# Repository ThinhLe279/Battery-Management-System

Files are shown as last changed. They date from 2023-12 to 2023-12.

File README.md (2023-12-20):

# BATTERY MANAGEMENT SYSTEM 
This project repository contains the firmware for the Battery Management System (BMS), utilizing an `STM32L152RE` microcontroller board to oversee the conditions of four LiFePo4 cells arranged in series, including voltage, current, and temperature. Depending on the monitored conditions, the microcontroller directs the battery current flow into charging-only, discharging-only, or bidirectional modes. A Modbus slave/server protocol was implemented for data communication. A Python script acting as a Modbus Master was created on a Raspberry Pi to serve as a gateway, retrieving status data from the BMS and transmitting it to the cloud for visualization. Grafana was employed as the cloud service for visualization purposes.

## Table of Content  
	
	1. Main Equipment and Components 

	2. Functionalities

	3. Details 

## 1. Main Equipments and Components

* `STM32L152RE` (development board)
* `RASPBERRY PI`
* OP AMPS `LM342`
* MOSFET `FDS6898AZ`
* Multiplexer `4051BE`
* Shunt Resistor `WLBR010FE`
* Temperature Sensor `LM35DZ`

## 2. Functionalities

The Battery Management System (BMS) oversees and regulates multiple facets of the battery's condition to ensure both safety and optimal functionality, covering:
* Voltage Monitoring:
	* Tracking the individual cell and theoverall voltage of the battery.
* Temperature Monitoring:
	* Supervise Environment and Battery Pack's temperature.
* Current Supervision:
	* Overseeing the direction and intensity of current flow in and out of the battery. pack.
* Cell Balancing:
	* Maintaining a balanced state among the battery cells.
* Charging and Discharging Management:
	* Regulate MOSFETS to control the charging and discharging states of the battery.

## 3. Details
### Prerequisites
The project requirements: `MOSFET` driven switch (both charging and discharging) Temperature monitoring Individual battery cell voltages STM32 controller with over/under voltage per cell, over/under temperature (charge: 0C to 40C and discharge: -20C to 40C) Communication of cell voltages/temperatures/... over Modbus RTU protocol with the `STM32L152RE` functioning as a Slave and the `Raspberry Pi` serving as the Master.

Presentation of data on Grafana through a Docker container on the Raspberry Pi.

### Project diagram 

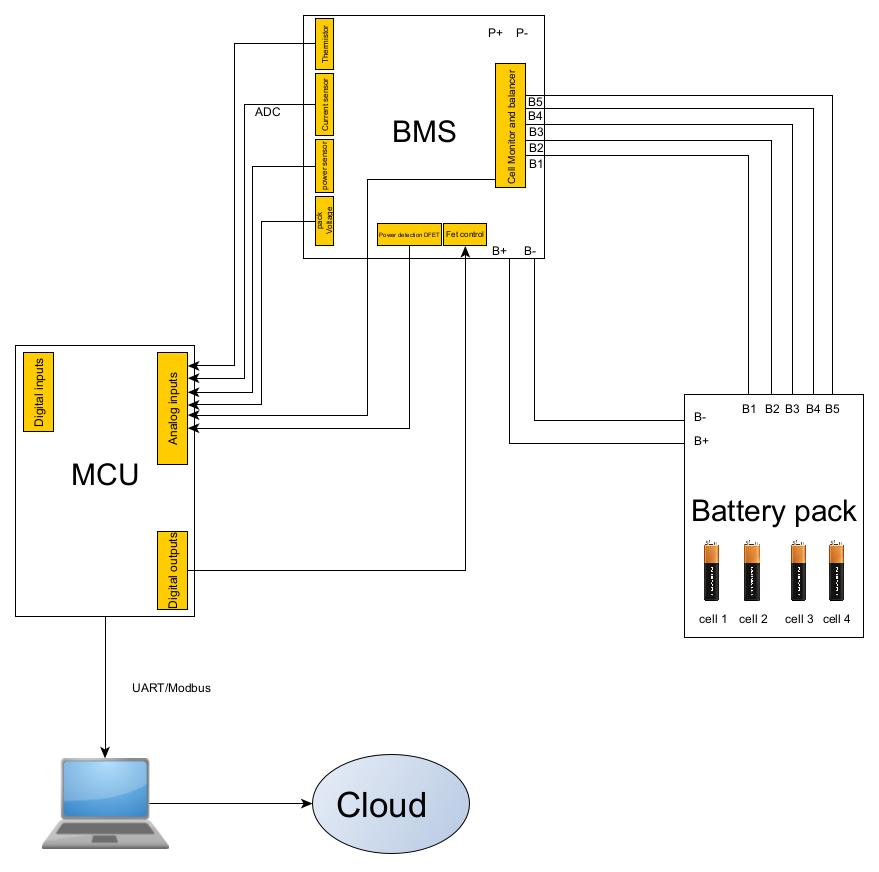
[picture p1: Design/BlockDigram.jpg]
diagram


### visualization

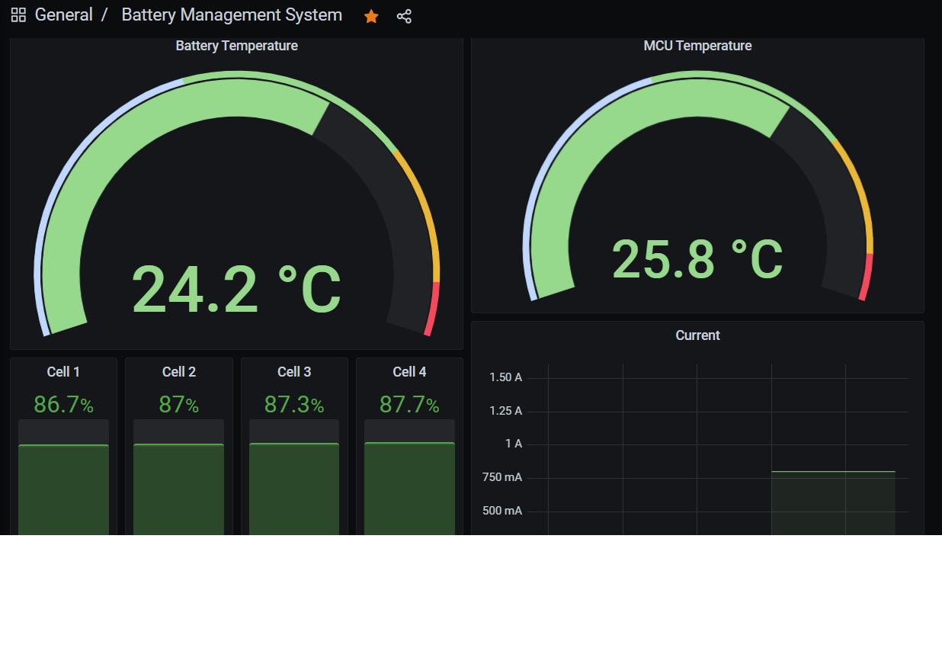
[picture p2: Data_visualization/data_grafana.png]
display


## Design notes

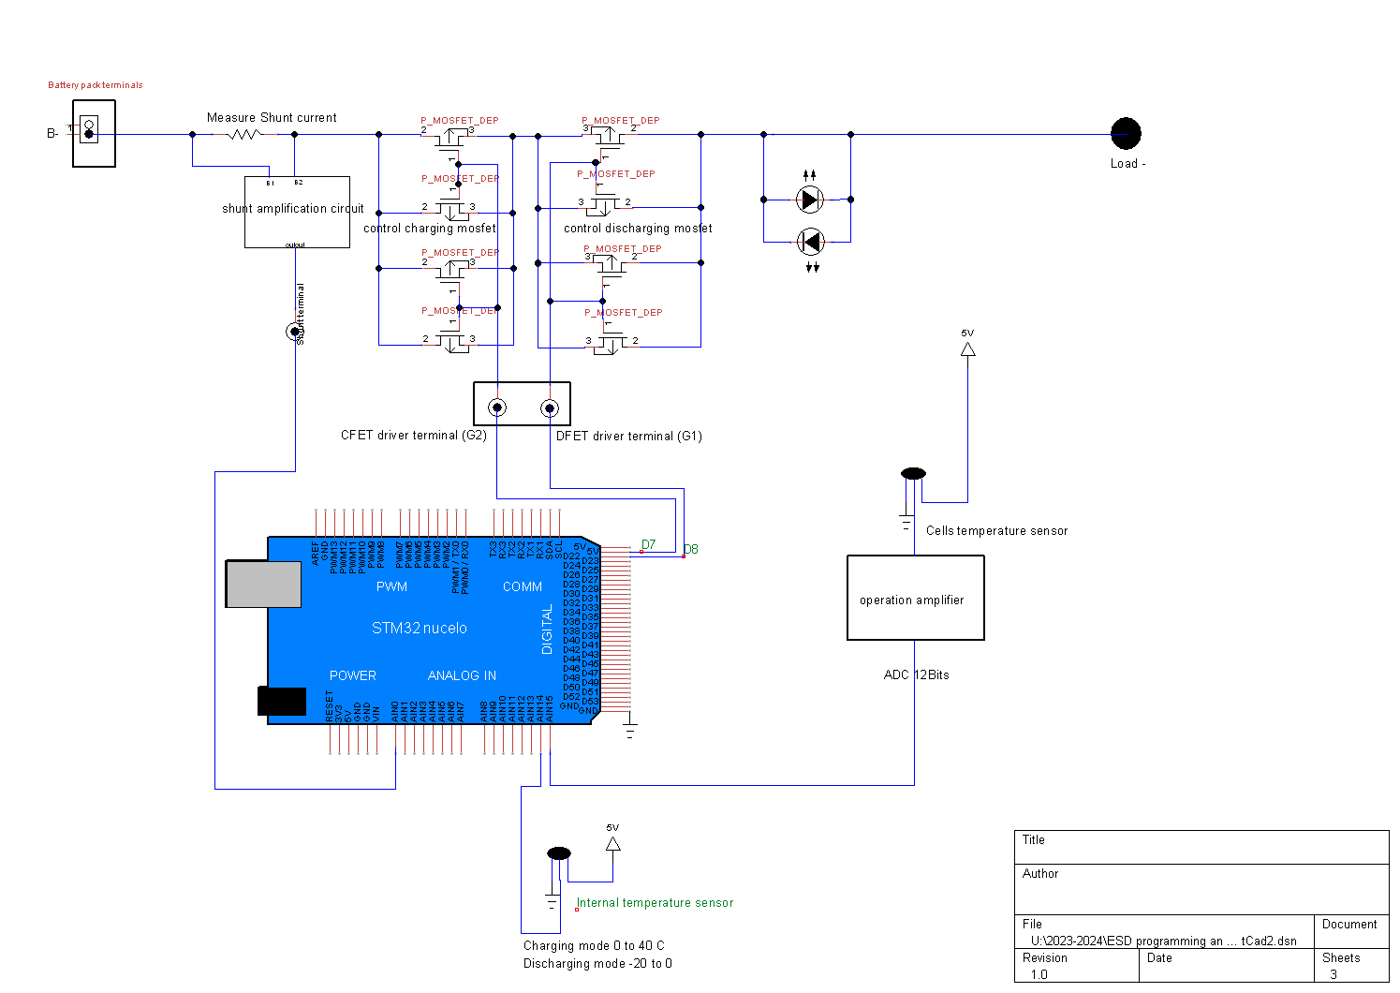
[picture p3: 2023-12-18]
schematic/IMG/tCad2.png

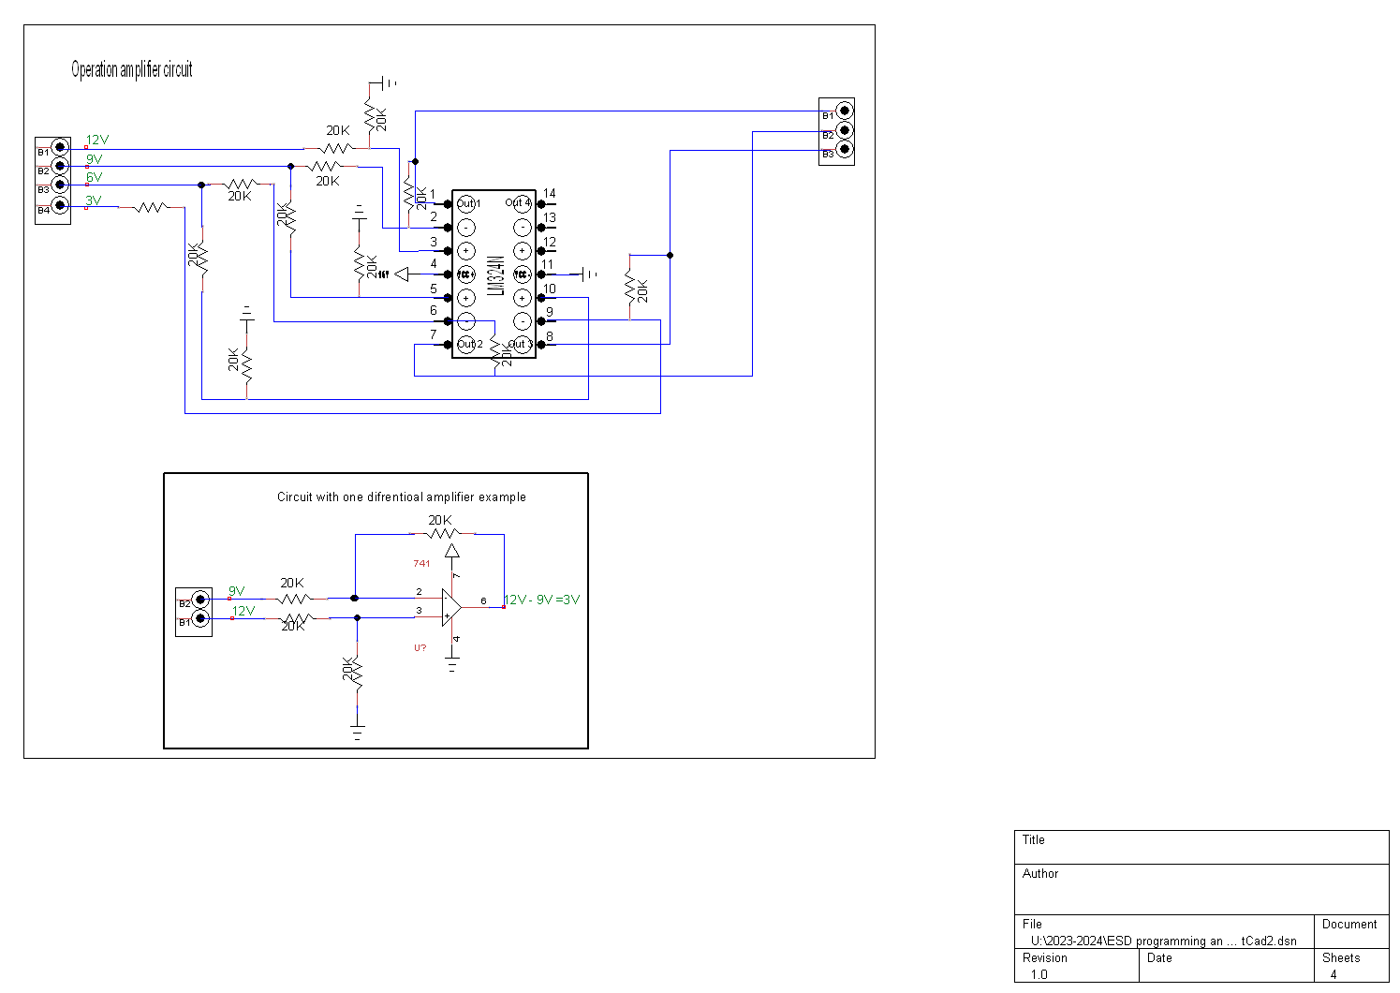
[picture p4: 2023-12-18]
schematic/IMG/Cells Voltages.png

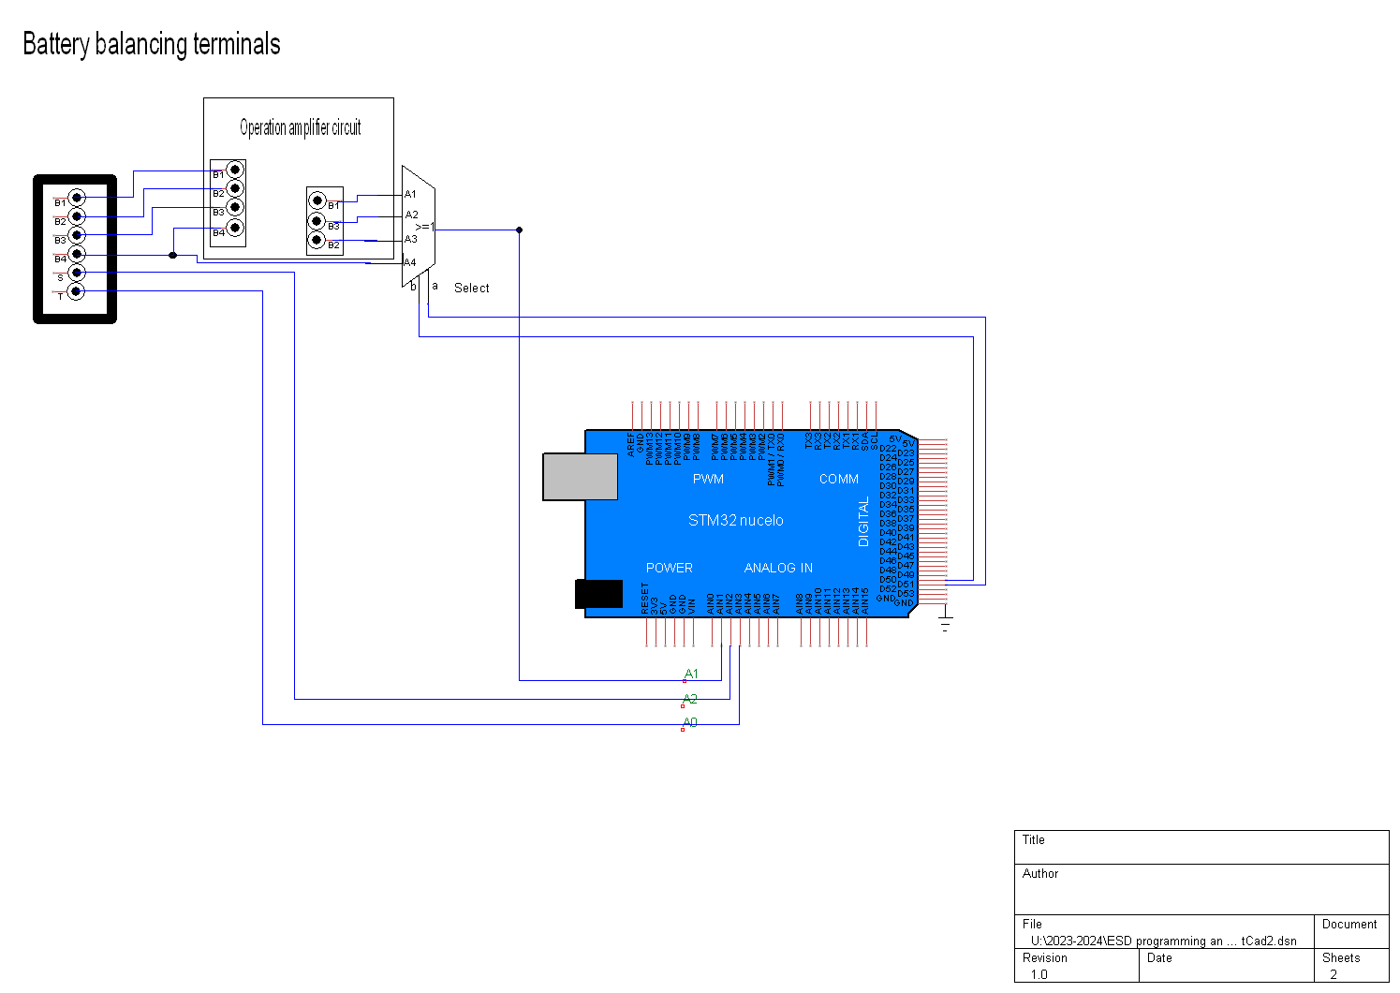
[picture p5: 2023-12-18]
schematic/IMG/MUX Connections.png

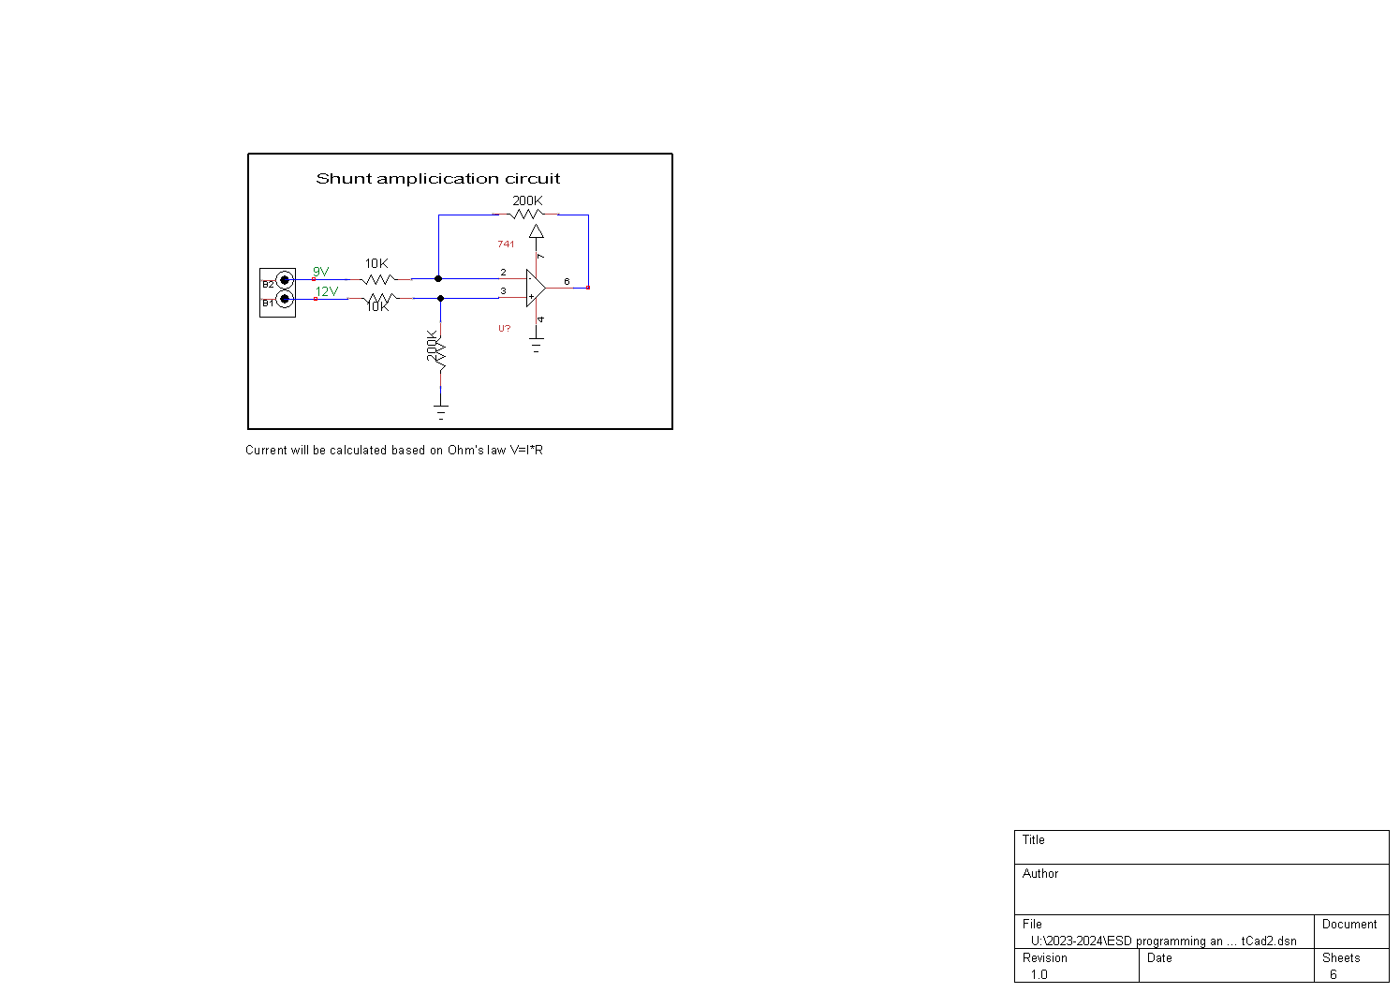
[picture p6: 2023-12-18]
schematic/IMG/Shunt amp circuit.png

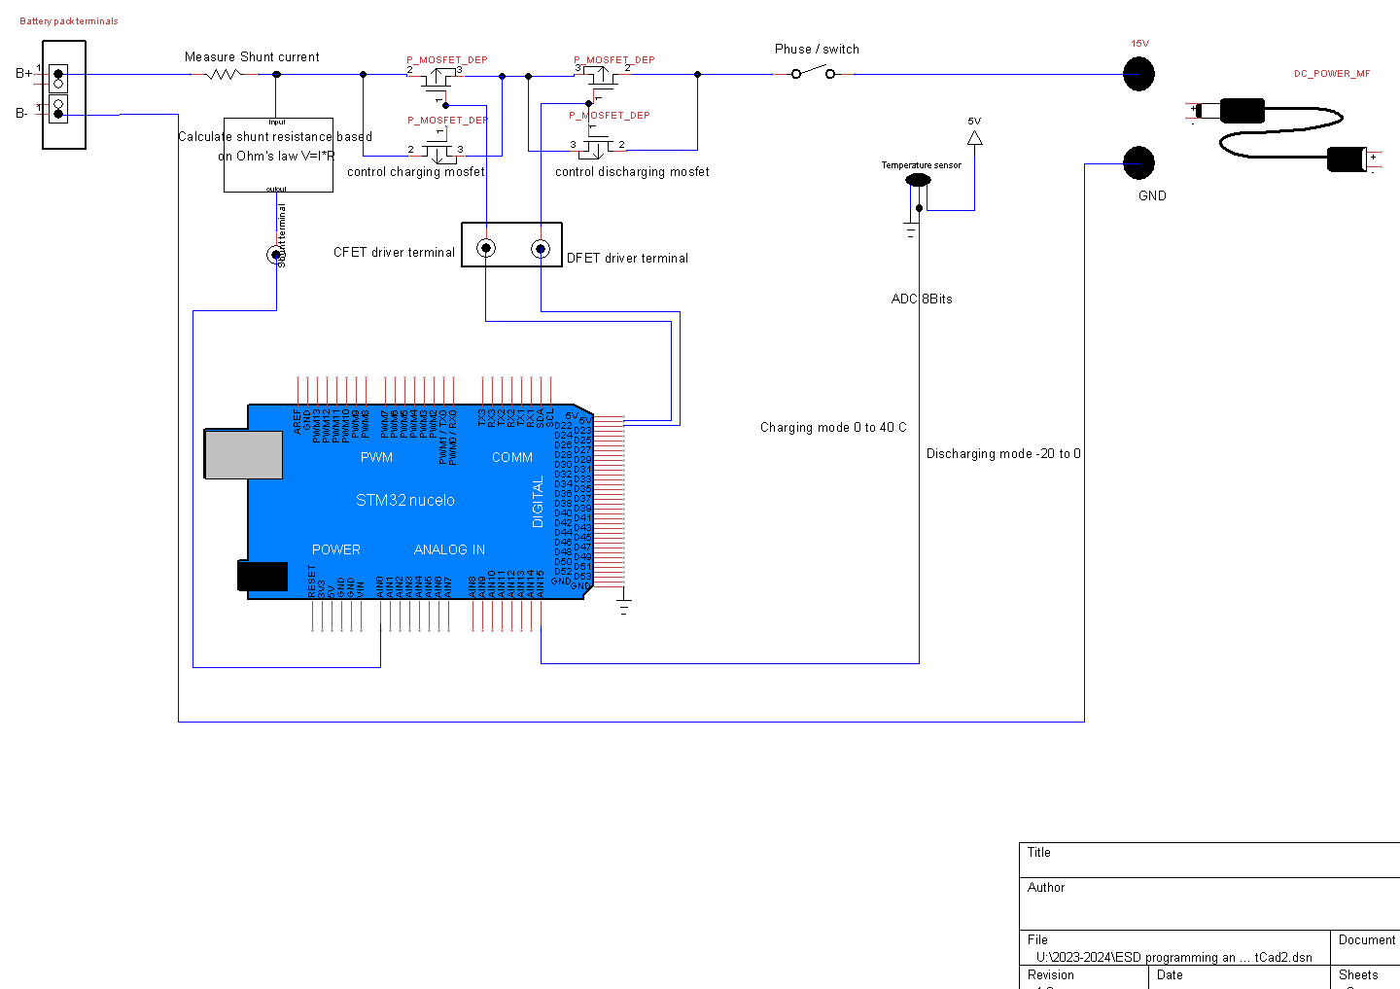
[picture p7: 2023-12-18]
schematic/IMG/SOC.png

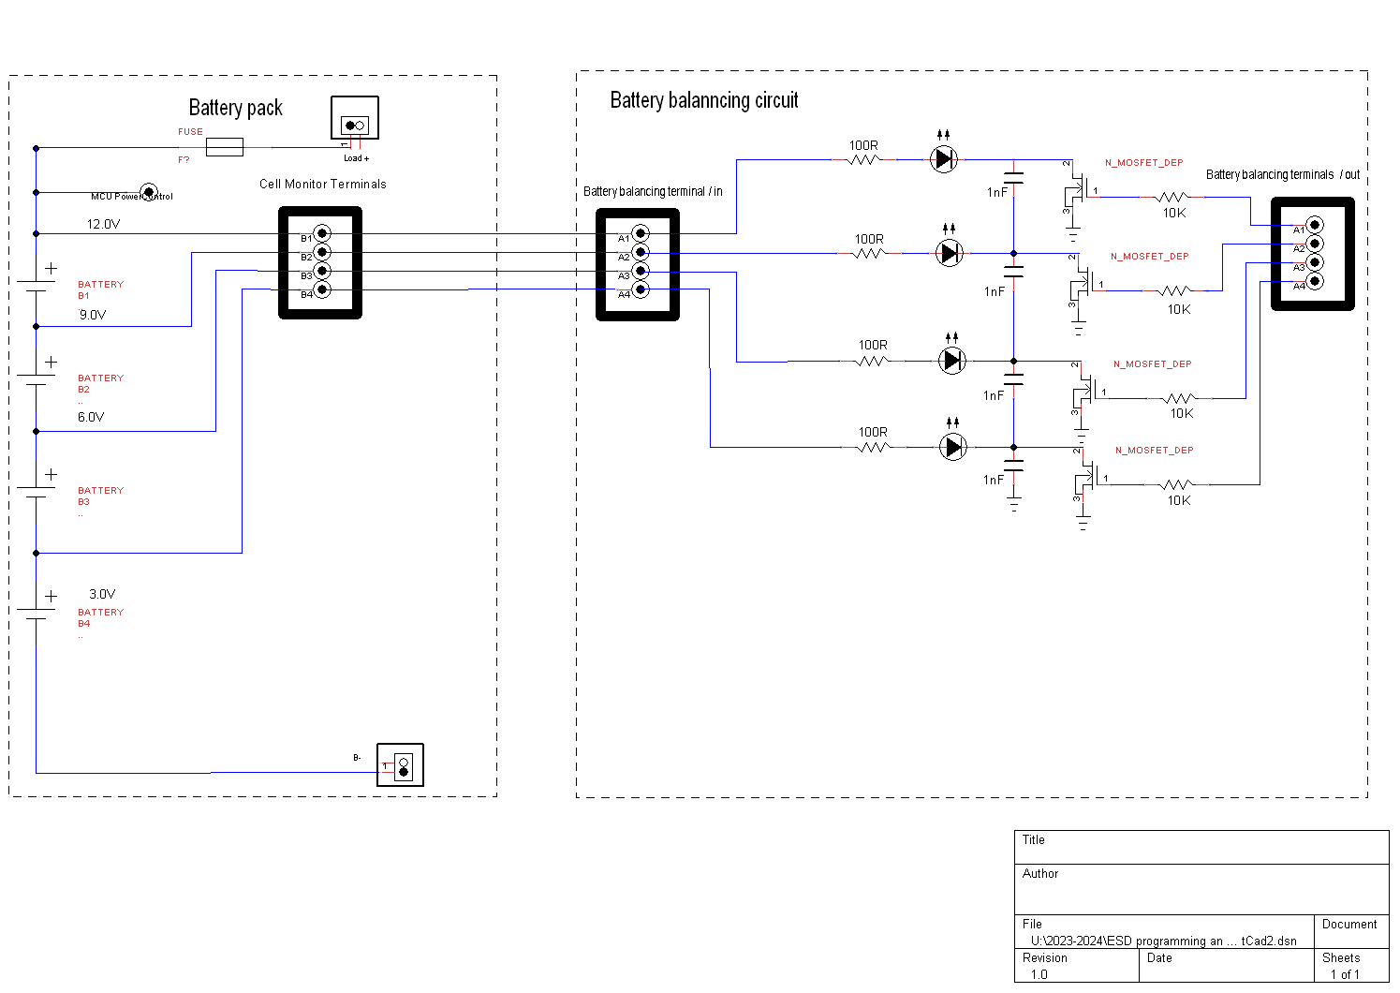
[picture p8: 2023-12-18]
schematic/IMG/Battery pack.png

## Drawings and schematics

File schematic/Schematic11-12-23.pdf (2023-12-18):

A4 Battery balanncing circuit | 3 2

# Battery pack

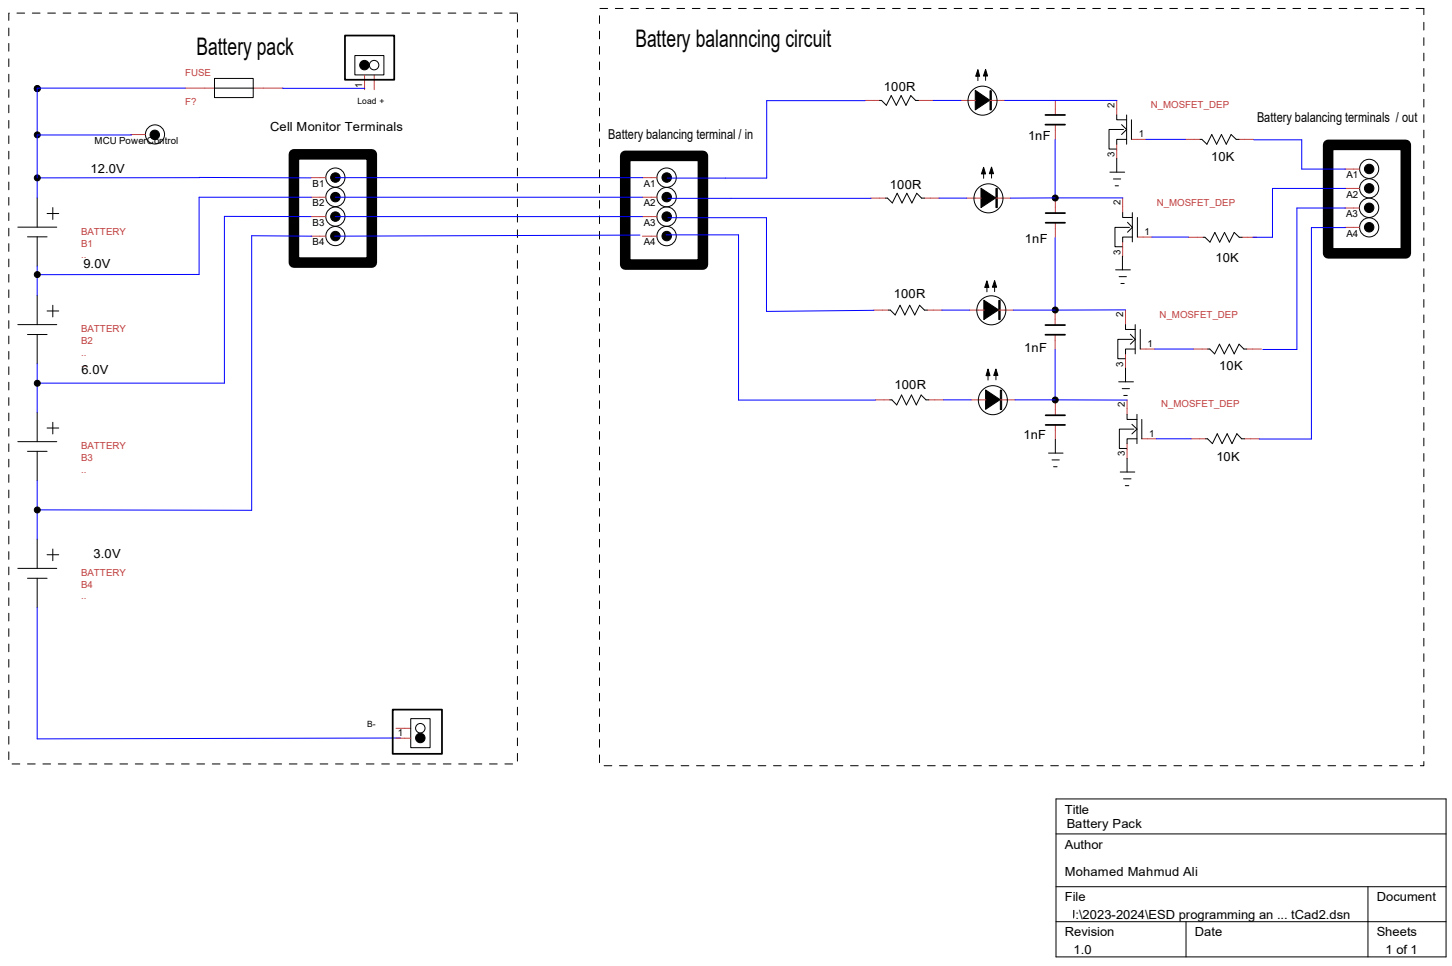
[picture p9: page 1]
BATTERY; N_MOSFET_DEP 3 2; N_MOSFET_DEP; Load +; FUSE; MCU PowerControl; Battery Pack; Title; Author

Battery balancing terminals / out

B4 Cell Monitor Terminals

A4 Battery balancing terminal / in

Mohamed Mahmud Ali

File U:\2023-2024\ESD programming an ... tCad2.dsn | Document

Revision 1.0 1 of 1 | Date | Sheets

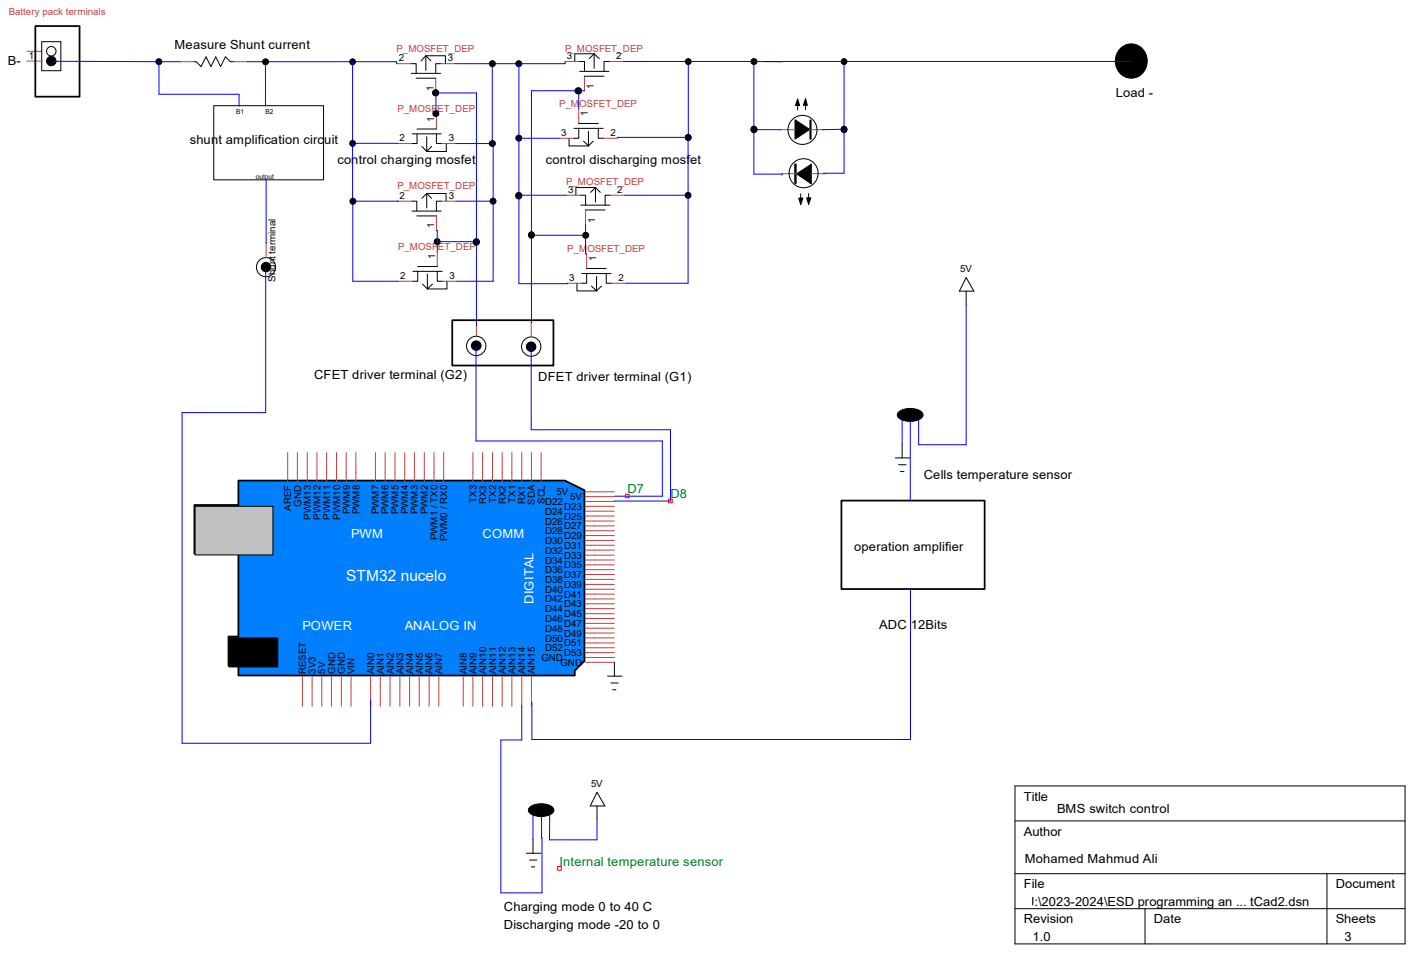
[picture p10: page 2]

File U:\2023-2024\ESD programming an ... tCad2.dsn | Document

Revision 1.0 3 | Date | Sheets

# Battery balancing terminals

# S Operation amplifier circuit

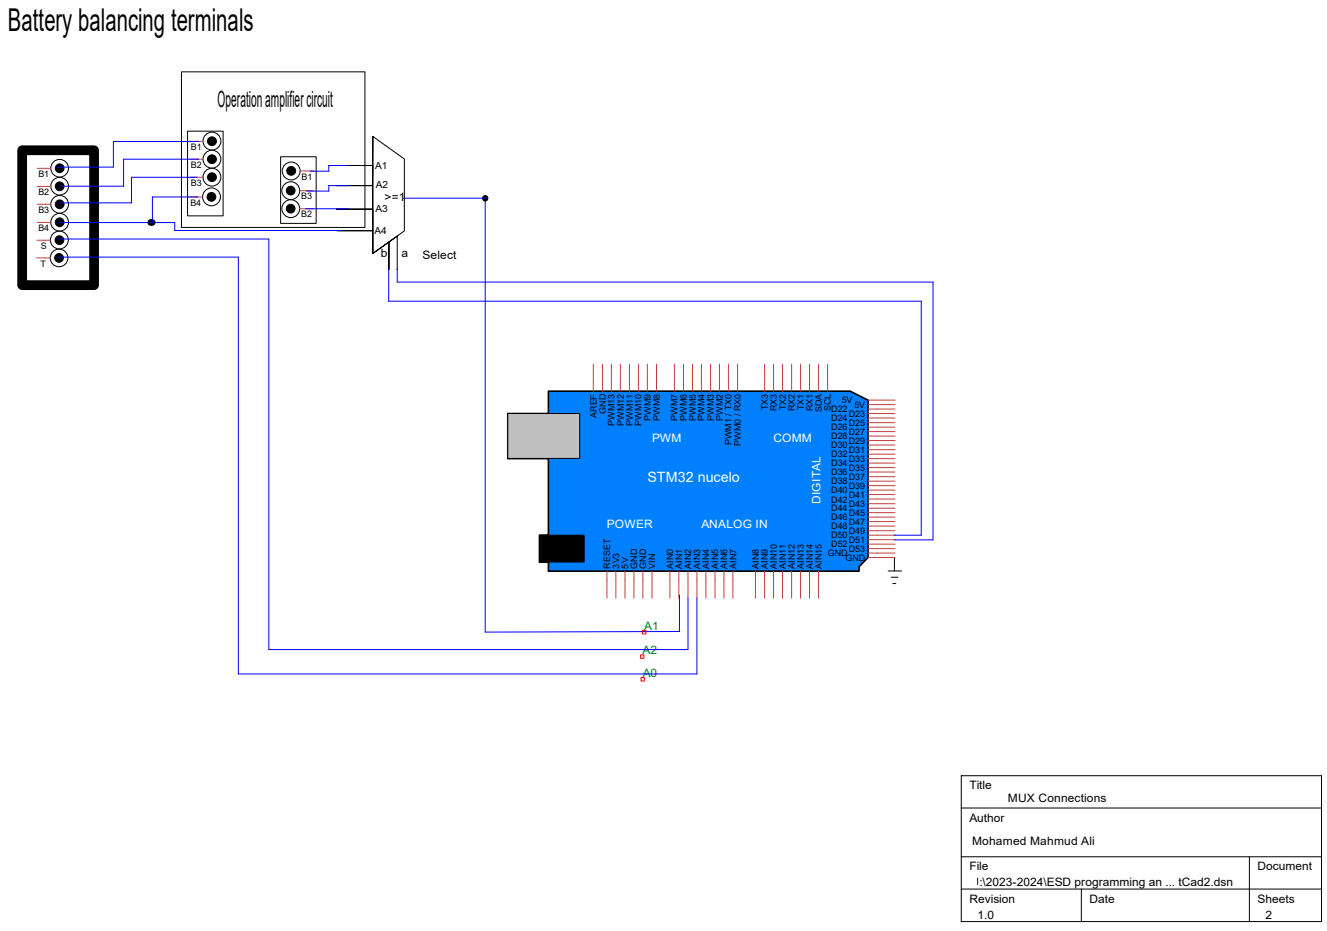
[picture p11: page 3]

File U:\2023-2024\ESD programming an ... tCad2.dsn | Document

Revision 1.0 2 | Date | Sheets

# Operation amplifier circuit

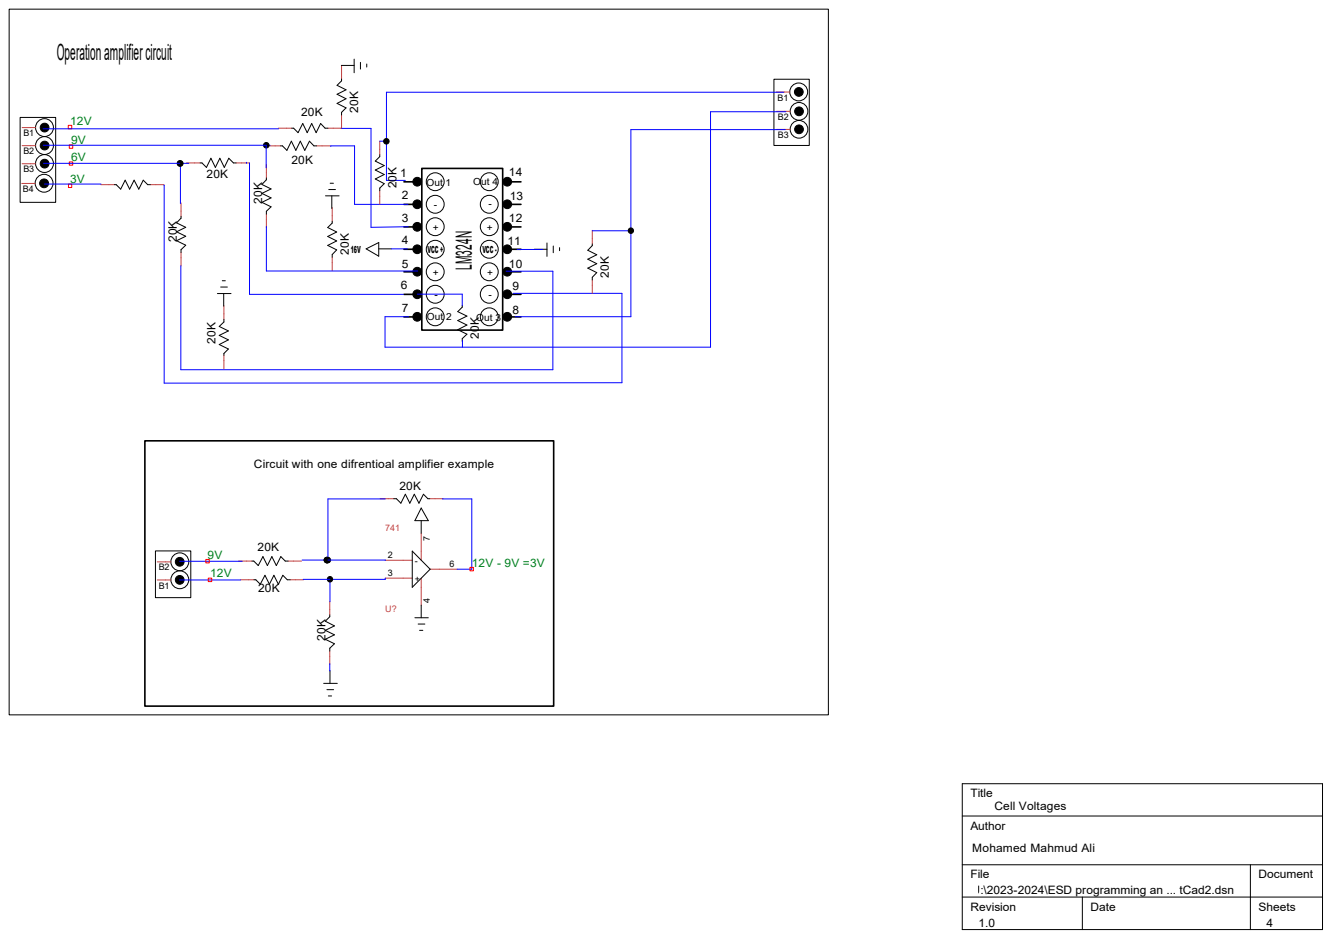
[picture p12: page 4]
B2 B3 LM³²⁴N VCC +; 14 Out 1 Out 2; Out 3 Out 4; +VCC -

Circuit with one difrentioal amplifier example

Title
Cell Voltages
Author
Mohamed Mahmud Ali

File U:\2023-2024\ESD programming an ... tCad2.dsn | Document

Revision 1.0 4 | Date | Sheets

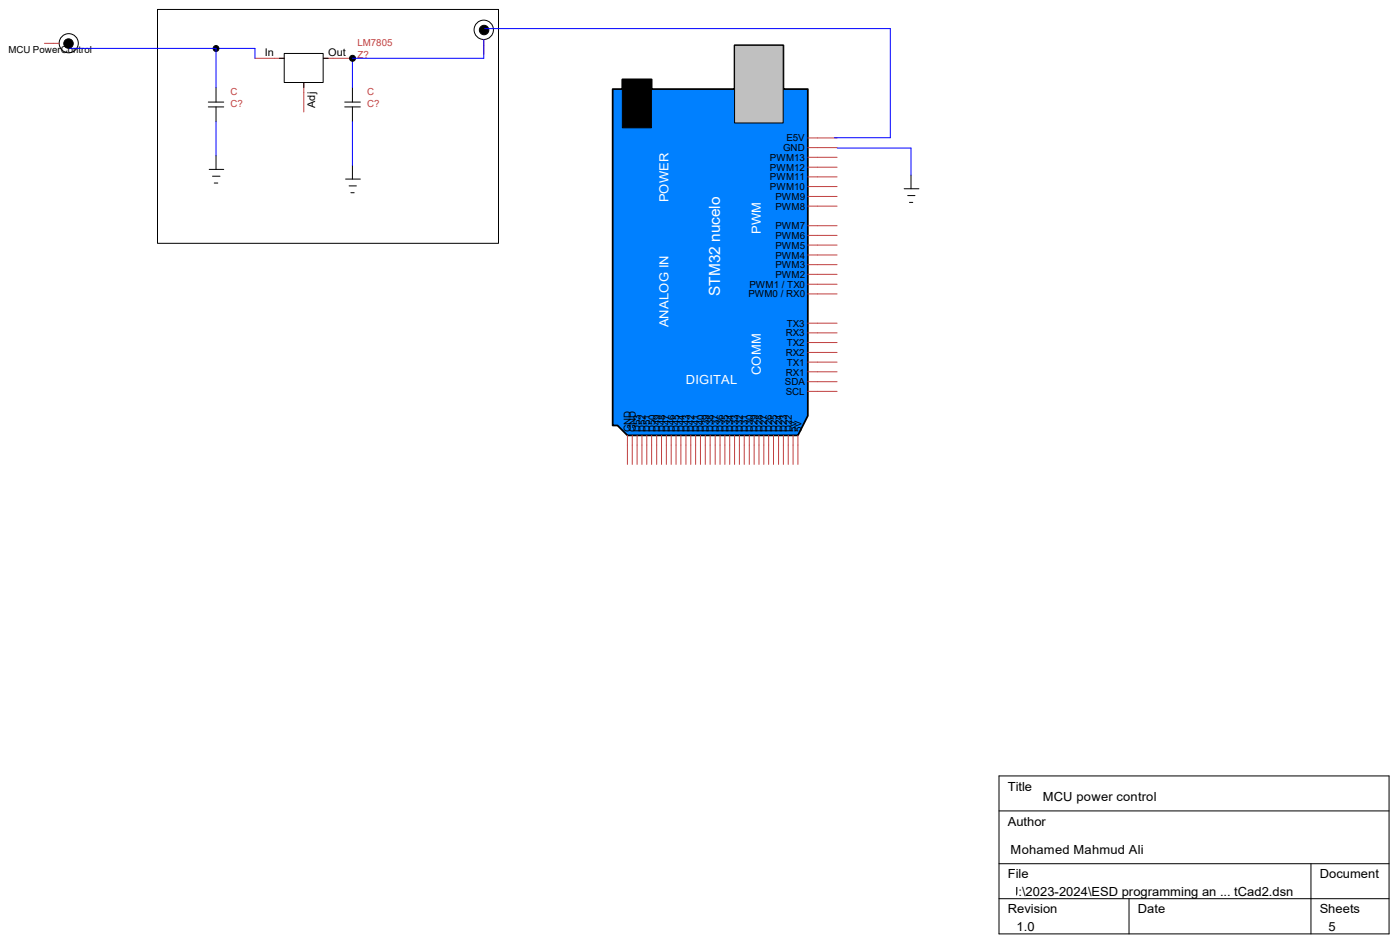
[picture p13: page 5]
STM32 nucelo; E5V GND; PWM2; PWM3; PWM4; PWM5; PWM6; PWM7; PWM8; PWM9; PWM10; PWM11; PWM12; PWM13; PWM0 / RX0; PWM1 / TX0; SCL; SDA; TX3 GND GND; D⁵⁰ D⁴⁹ D⁴⁸ D⁴⁷ D⁴⁶ D⁴⁵ D⁴⁴ D⁴³ D⁴² D⁴¹ D⁴⁰ D³⁹ D³⁸ D³⁷ D³⁶ D³⁵ D³⁴ D³³ D³² D³¹ D³⁰ D²⁹ D²⁸ D²⁷ D²⁶ D²⁵ D²⁴ D²³ D²² 5V5V PWM COMM DIGITAL ANALOG IN POWER D⁵³ D⁵² D⁵¹; MCU PowerControl; Out Adj

Title
MCU power control
Author

Mohamed Mahmud Ali

File U:\2023-2024\ESD programming an ... tCad2.dsn | Document

Revision 1.0 5 | Date | Sheets

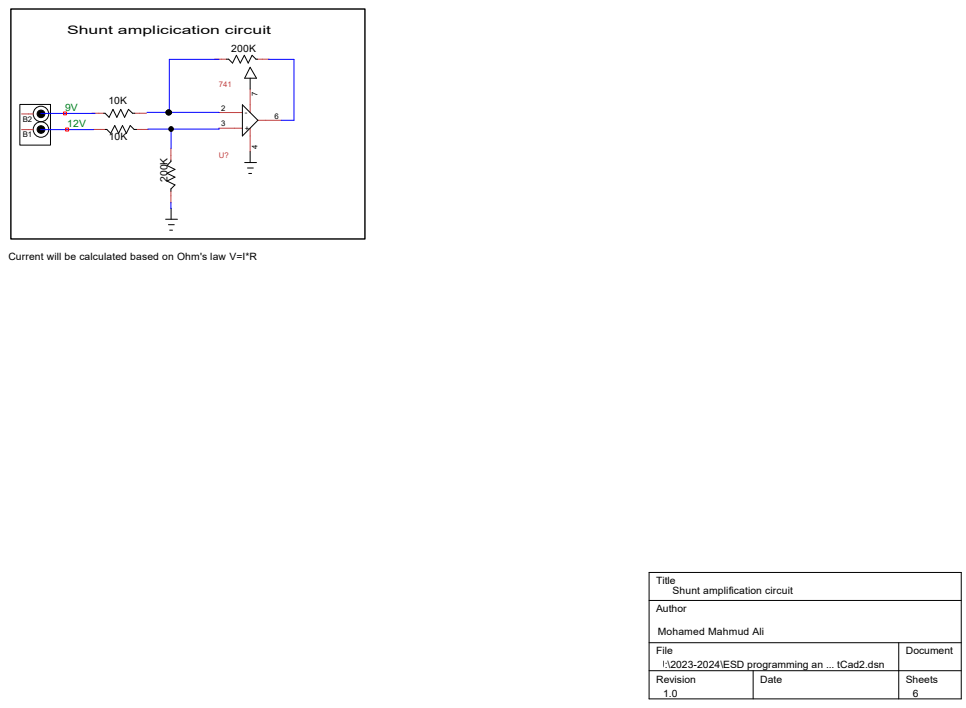
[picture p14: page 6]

Shunt amplicication circuit 4

Current will be calculated based on Ohm's law V=I*R

Title
Shunt amplification circuit
Author

Mohamed Mahmud Ali

File U:\2023-2024\ESD programming an ... tCad2.dsn | Document

Revision 1.0 6 | Date | Sheets

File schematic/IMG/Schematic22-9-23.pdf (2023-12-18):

A4 Battery balanncing circuit | 3 2

# Battery pack

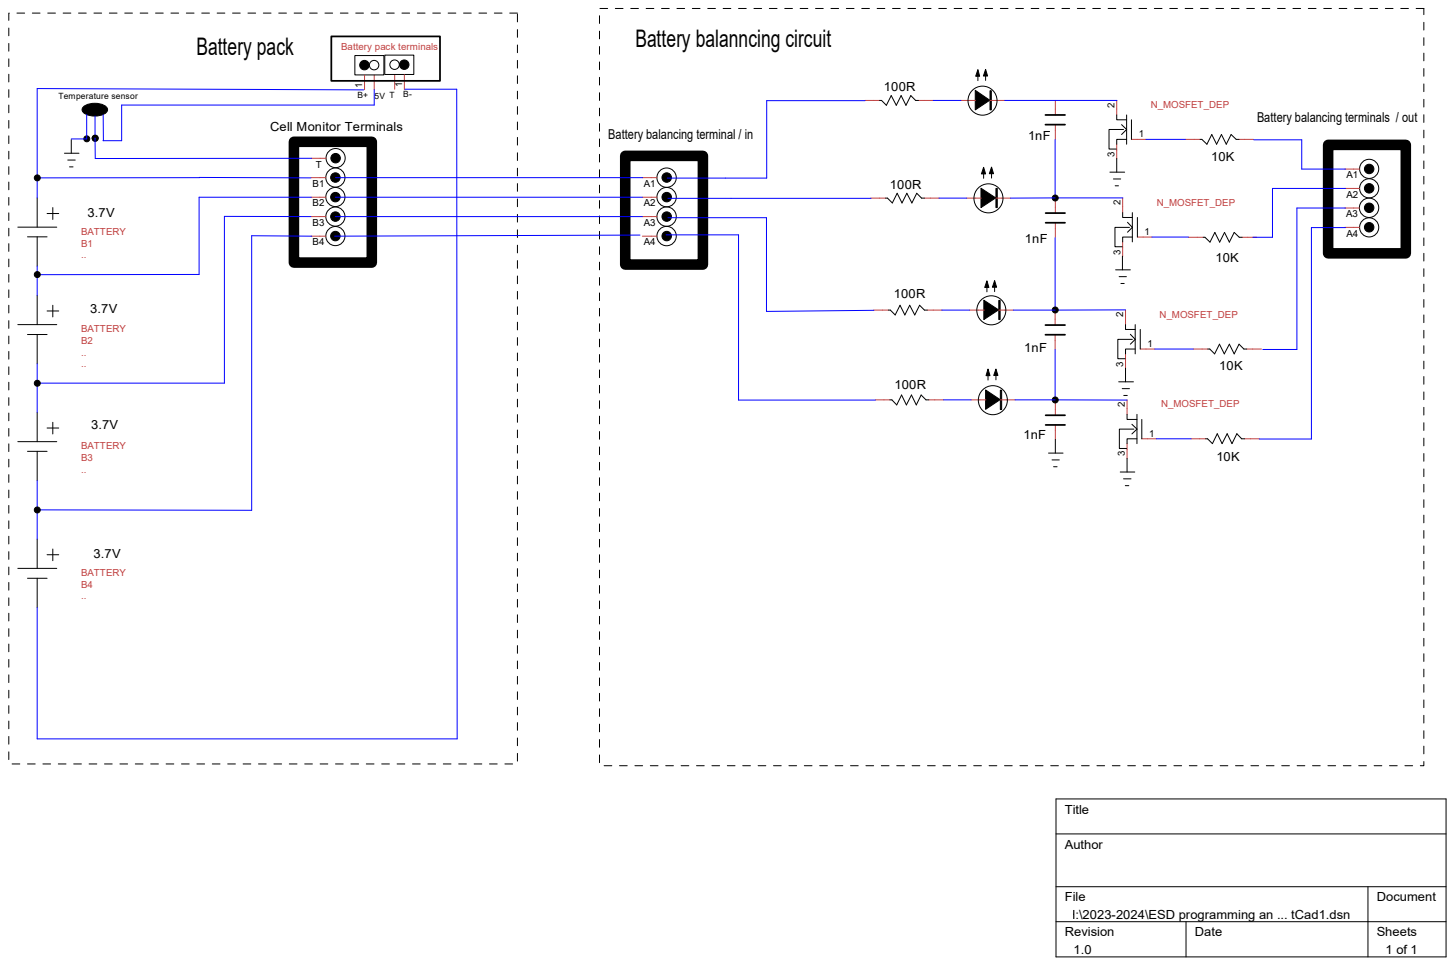
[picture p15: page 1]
BATTERY; N_MOSFET_DEP 3 2; N_MOSFET_DEP; Temperature sensor; Title; Author

Battery pack terminals B+

Battery balancing terminals / out ¹

B4 Cell Monitor TerminalsB-

A4 Battery balancing terminal / in

File H:\2023-2024\ESD programming an ... tCad1.dsn | Document

Revision 1.0 1 of 1 | Date | Sheets

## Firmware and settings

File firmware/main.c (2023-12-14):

/* Includes */
#include <stddef.h>
#include <stdio.h>
#include "stm32l1xx.h"
#include "nucleo152start.h"

#include "ADC_measurement.h"
#include "battery_protect.h"
#include "USART2_DMA_Config.h"
#include "modbus.h"

int flag = 0;		// global flag for MODBUS activities
int main(void) {

	__disable_irq();		//global disable IRQs, M3_Generic_User_Guide p135.
	/* Configure the system clock to 32 MHz and update SystemCoreClock */
	SetSysClock();
	SystemCoreClockUpdate();
	USART2_Init();
	DMA_Init();
	__enable_irq();		//global enable IRQs, M3_Generic_User_Guide p135

	Adc_set_up();	// set up ADC for measurements
	Mux_set_up();	// set up for the multiplexer
	MFET_set_up();	// set up C_FET and D_FET

	float Int_temp = 0;
	float LM35_temp = 0;
	float cell_vol[4] = { 0, 0, 0, 0 };
	float shunt = 0;

	MODBUS Mod;		// modbus object

	// reset pin A and B of the multipler
	GPIOA->ODR &= ~(1 << Select_Pin_B);
	GPIOA->ODR &= ~(1 << Select_Pin_A);

	/* Infinite loop */
	while (1) {

		switch (flag) {
		case 0:
			break;

		case 1:
			//display("slave address is correct");
			Modbus_routine(&Mod);
			Restart_DMA();
			Reset_DMA_RX_BUFFER();
			USART2->CR1 |= (1 << 2);	////re-enable USART2 RE
			flag = 0;
			break;

		case 2:
			//display("wrong address");
			Restart_DMA();
			Reset_DMA_RX_BUFFER();
			USART2->CR1 |= (1 << 2);	//re-enable USART2 RE
			flag = 0;
			break;
		}
		shunt = Read_shunt_resistor();
		delay_Ms(200);
		Mod.shunt = (int) (shunt * 10);	// update shunt value for modbus protocol
		Current_check(shunt);// check for batter protection (baterry_protect.c)

		Int_temp = Internal_Temp_Read();
		delay_Ms(200);
		Mod.int_temp = (int) (Int_temp * 10);// update int_temp value for modbus protocol
		INT_Temperature_check(Int_temp);// check for batter protection (baterry_protect.c)

		LM35_temp = LM35_Temp_read();
		delay_Ms(200);
		Mod.LM35_temp = (int) (LM35_temp * 10);	// update LM35_temp value for modbus protocol
		LM35_temperature_check(LM35_temp);// check for batter protection (baterry_protect.c)

		for (int i = 0; i < 4; i++) {
			Select_mux_pin(i);		// select pin in multiplexer
			cell_vol[i] = Read_Cell_Voltage();
			delay_Ms(200);
			Mod.cell_vol[i] = (int) (cell_vol[i] * 10);	// update cells voltage value for modbus protocol
		}
		Batt_cells_check(cell_vol);	// check for batter protection (baterry_protect.c)

		BMS_Operation();// batter protection activities after sensing all the value, (battery_protect.c)

		delay_Ms(1000);

	}
	return 0;
}

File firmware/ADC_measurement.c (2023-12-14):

/*
 *
 *  Created on: Oct , 2023
 *      Author: Thinh Le
 */
#include "ADC_measurement.h"

/* Define an array for select pins */
const int selectPins[2] = { Select_Pin_A, Select_Pin_B };

void Adc_set_up() {

	// set Analog pin
	RCC->AHBENR |= 1;					// enable GPIOA clock
	GPIOA->MODER |= 0x3;				// PA0 for LM35		A0
	GPIOA->MODER |= (1 << 3) | (1 << 2); // PA1 for the multiplexer		A1
	GPIOA->MODER |= (1 << 9) | (1 << 8); // PA4 for the Shunt resistor.		A2
	// setup ADC1 and temp sensor. p287
	RCC->APB2ENR |= 0x00000200; // enable ADC1 clock
	// set the resolution
	ADC1->CR1 &= ~0x03000000; // resolution 12-bit
	// set the sampling rate
	ADC1->SMPR3 = 7;		// sampling time longest 384 cycles for channel 0
	ADC1->SMPR3 |= (1 << 3) | (1 << 4) | (1 << 5);// sampling time longest 384 cycles for channel 1
	ADC1->SMPR3 |= (1 << 12) | (1 << 13) | (1 << 14);// sampling time longest 384 cycles for channel 4
	ADC1->SMPR2 |= (1 << 18) | (1 << 19) | (1 << 20); // sampling time longest 384 cycles for channel 16
	// set single-mode , bit 11 = 0 align right
	ADC1->CR2 = 0;
	// enable temp sensor
	ADC->CCR |= (1 << 23);
}

void Mux_set_up() {
	// set select pins

	GPIOA->MODER |= (1 << 10); // pin PA5 as Output   D13 	(B)
	GPIOA->MODER |= (1 << 12); // pin PA6 as Output   D12	(A)
}

void MFET_set_up() {
	GPIOA->MODER |= (1 << 16); // pin PA8 for C_FET  D7
	GPIOA->MODER |= (1 << 18); // pin PA9 for D_FET  D8
}

void Select_mux_pin(int channel) {
	for (int i = 0; i < 2; i++) {
		if (channel & (1 << i)) {
			GPIOA->ODR |= (1 << selectPins[i]);
		} else
			GPIOA->ODR &= ~(1 << selectPins[i]);
	}
}

float Read_Cell_Voltage(void) { // this functions return voltage of a cell in mV
	int result = 0;
	float mili_volt = 0;
	ADC1->SQR5 = 1;	// Set the conversion sequence to start at the specified channel
	ADC1->CR2 |= 1;			 // Bit 0, ADC on/off (1=on, 0=off)
	ADC1->CR2 |= 0x40000000; // Start conversion
	while (!(ADC1->SR & 2)) {
	}				   // Wait for conversion complete
	result = ADC1->DR; // Read conversion result

	mili_volt = ((result * 3.3) / 4095.0) * 1000;

	ADC1->CR2 &= ~1; // bit 0, ADC on/off (1=on, 0=off)

	return mili_volt;
}

float Read_shunt_resistor(void) {	// this function to read the current from Shunt ( in mA)

	int result = 0;
	ADC1->SQR5 = 4;	// Set the conversion sequence to start at the specified channel
	ADC1->CR2 |= 1;			 // Bit 0, ADC on/off (1=on, 0=off)
	ADC1->CR2 |= 0x40000000; // Start conversion
	while (!(ADC1->SR & 2)) {
	}				   // Wait for conversion complete
	result = ADC1->DR; // Read conversion result
	// I just return the ADC value of this channel, you need to apply your fomula to calculate the current

	ADC1->CR2 &= ~1; // bit 0, ADC on/off (1=on, 0=off)
	float vol = (result / 4095.0) * 3.3;
	float value1 = vol / 1000.0;
	float current = value1 / 0.01;

	return current * 1000;	// return in mA

}

float Internal_Temp_Read() {
	int result = 0;	 // store adc value
	ADC1->SQR5 = 16; // SQ1 for channel 16 (internal sensor)
	ADC1->CR2 |= 1;	 // bit 0, ADC on/off (1=on, 0=off)

	ADC1->CR2 |= 0x40000000; // start conversion
	while (!(ADC1->SR & 2))
		; // wait for conversion to complete

	result = ADC1->DR;

	float result2 = (110.0 - 30.0) / ((float) TS_CAL2 - (float) TS_CAL1)
			* ((float) result - (float) TS_CAL1) + 50.0;

	ADC1->CR2 &= ~1; // bit 0, ADC on/off (1=on, 0=off)

	return result2;
}

float LM35_Temp_read() {
	int result = 0;
	ADC1->SQR5 = 0;			 // SQ1 for channel (A0)
	ADC1->CR2 |= 1;			 // bit 0, ADC on/off (1=on, 0=off)
	ADC1->CR2 |= 0x40000000; // start conversion
	while (!(ADC1->SR & 2))
		; // wait for conversion to complete

	result = ADC1->DR;

	float voltage = (result / 4095.0) * 3.3;
	float temp = voltage * 13.33;
	ADC1->CR2 &= ~1; // bit 0, ADC on/off (1=on, 0=off)

	return temp;
}

void delay_Ms(int delay) {
	int i = 0;
	for (; delay > 0; delay--)
		for (i = 0; i < 2460; i++)
			; // measured with oscilloscope
}

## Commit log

2023-11-21 updated branch BMS_THINH
2023-11-22 update mosfet driving
2023-11-28 add battery management files
2023-11-28 done BMS protection and deriving mosfet
2023-12-07 the modbus is done (using DMA instead of USART RX interrupt), files are re-factorized,
2023-12-14 re-factorized the code, add comments and disable dislay function to make the program print nothing
2023-12-18 add schematic and design of project
    [BMS.kicad_pcb, BMS.kicad_sch, Logic0.sch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]
